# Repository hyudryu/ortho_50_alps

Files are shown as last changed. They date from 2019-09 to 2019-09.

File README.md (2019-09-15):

## Ortholinear 50% Keyboard: Alps Switch Plate and Case



#### Sample Layout:


#### Wiring Example:


#### Switch Plate:


#### Case Renders:




### 5x12 ortholinear keyboard switch plate for use with Alps switches.
* Inspired by the layout of the AMJ-40 keyboard, with an additional row for number keys.
* Kit works really well with an AEK-II, you can achieve a decent hacked together profile as pictured at the top.
* Bottom row intended to have a 2.75u spacebar and an adjacent 1.25u 3rd layer key.
* Spacerbar stabilizer mounting holes are designed for Alps OEM stabilizer not Cherry MX style stabs.
    * The spacebar can be mounted flipped, or normally.

### Assembly:
* The plate and case are intended to be joined with small screws, however, there are no holes in the parts. Feel free to add this but I chose to make them manually.
* The rear cutout is designed for a mini usb connection, like the one on the Teensy2.0.

### Note:
* Case cad files contain supports that will need to be trimmed off after printing, feel free to remove them if you want to print without them.
* Switch fitment is very tight when the plate is 3D printed at 2mm thickness. Trimming was definitely required in my case.
* Zero fitment guarantee, in fact, I guarantee you will have to fine tune the fit if printing.
* STL files may be misoriented for printing, thoroughly inspect files before continuing to print.
* Default firmware does not include any LED configuration.

###### Model was created in Solidworks, then exported as STL/DXF. Feel free to use/modify/redistribute.

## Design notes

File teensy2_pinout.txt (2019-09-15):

Using ATmega 32U4 controller:

Pins: row # : wire color
========================
F0 : r0 : wht
F1 : r1 : yel
F4 : r2 : red
F5 : r3 : grn
F6 : r4 : blu

Pins: column # : wire color
===========================
B7 : c0 : wht
D0 : c1 : yel
D1 : c2 : red
D2 : c3 : grn
D3 : c4 : blu
C6 : c5 : blk
C7 : c6 : blk
D7 : c7 : blu
B4 : c8 : grn
B5 : c9 : red
B6 : c10 : yel
F7 : c11 : wht

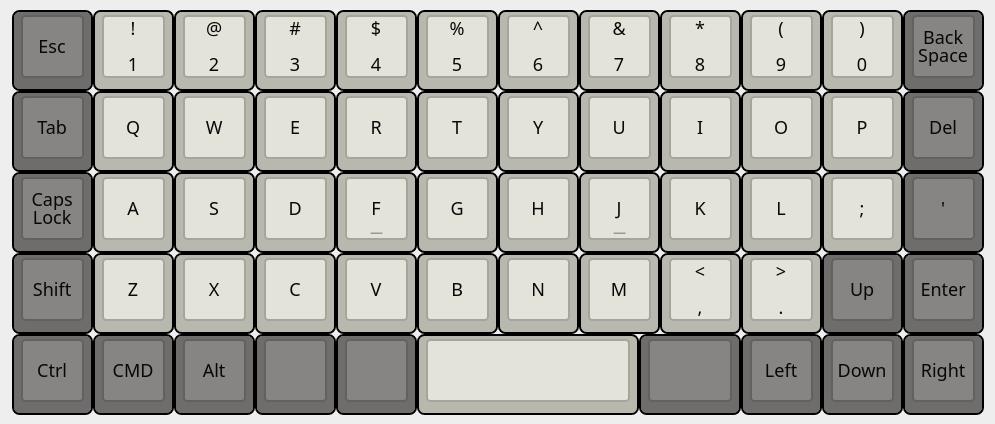
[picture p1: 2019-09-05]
ortho_50_layout.jpg

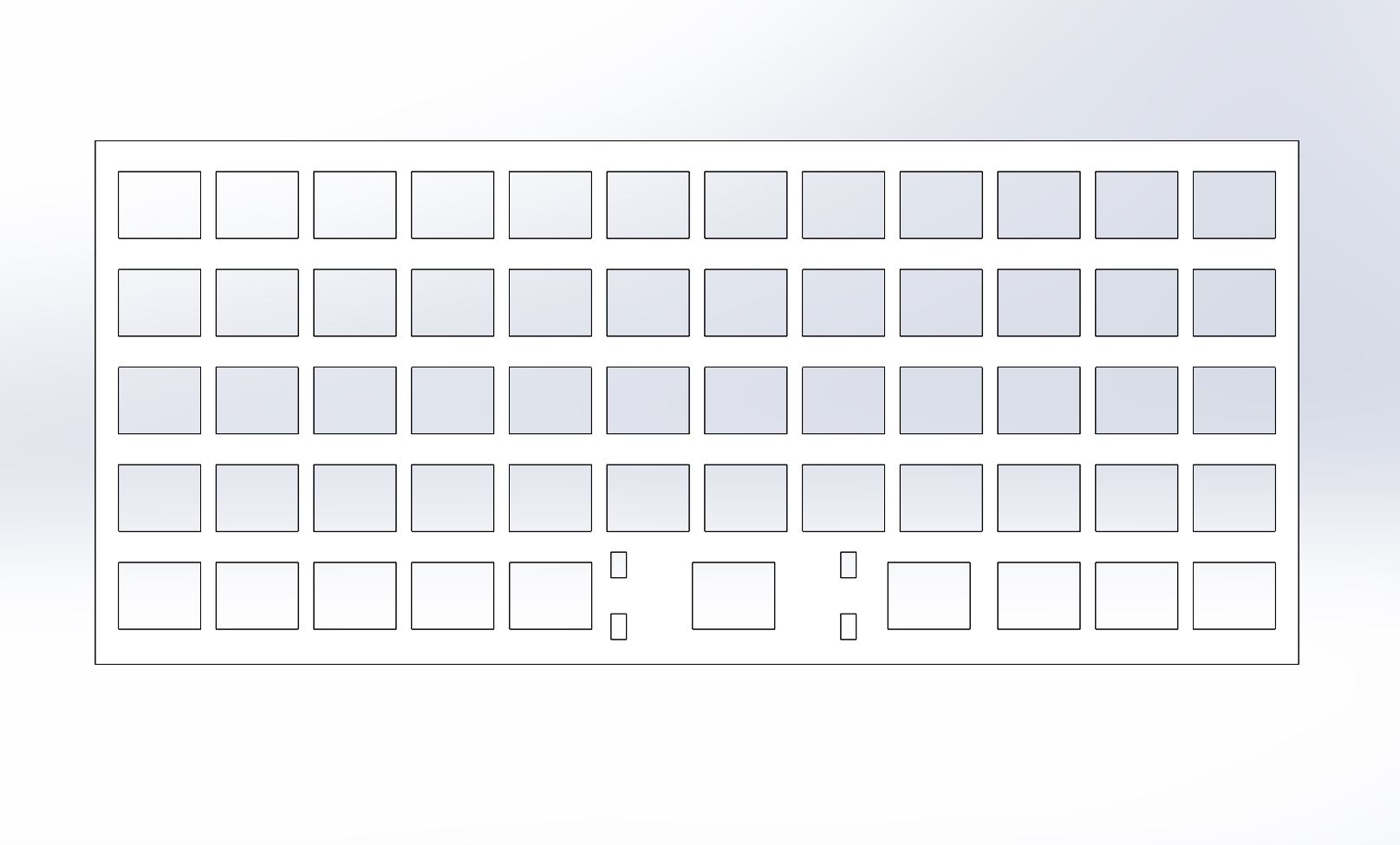
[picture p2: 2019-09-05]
ortho_50_plate.jpeg

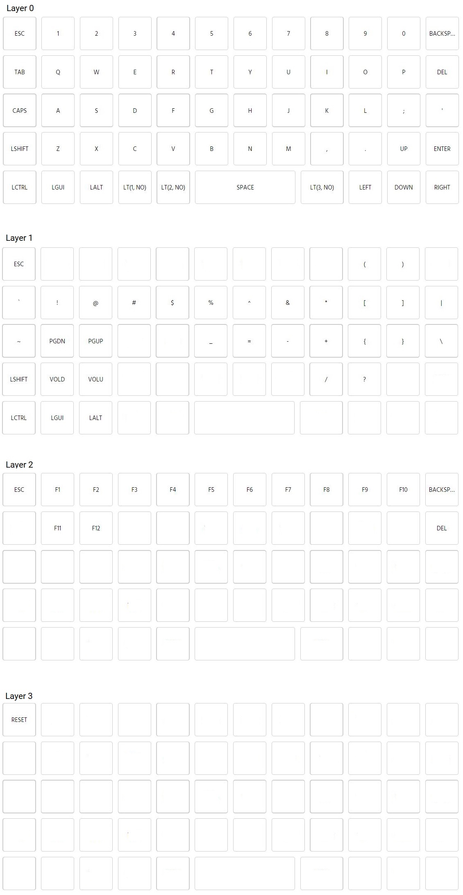
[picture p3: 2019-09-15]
ortho_50_keymap.jpg

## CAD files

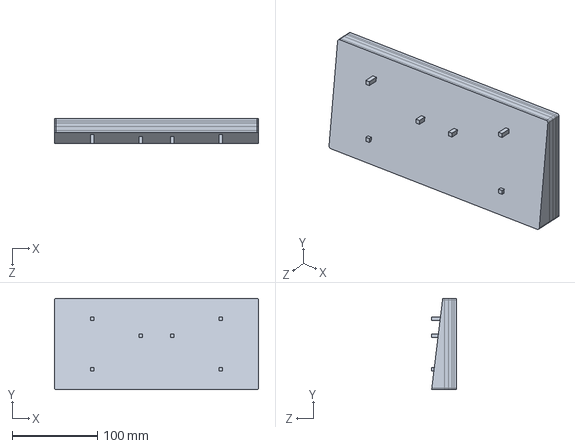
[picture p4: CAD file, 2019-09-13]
ortho_50_case.SLDPRT
239.0 x 106.8 x 29.0 mm

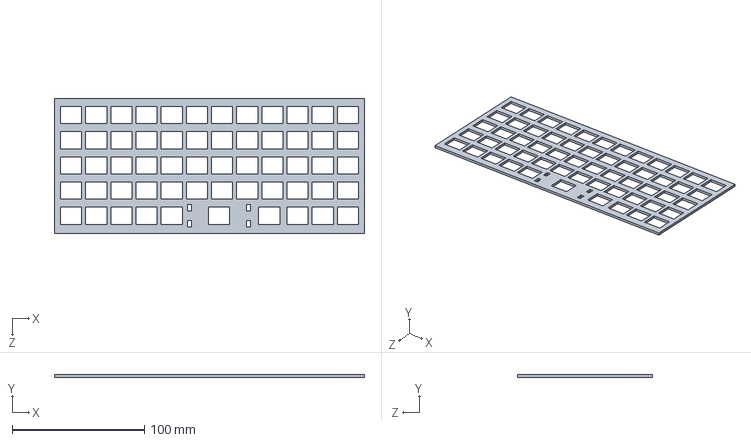
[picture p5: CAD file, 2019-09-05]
ortho_50_plate.SLDPRT
234.0 x 2.00 x 101.8 mm

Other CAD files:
ortho_50_case.STL
ortho_50_case.obj
ortho_50_plate.DXF
ortho_50_plate.STL

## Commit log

2019-09-06 added DXF file
    [aluminum_plate.DXF]
2019-09-12 added case files, added photo with aek caps
    [aluminum_plate.DXF, aluminum_plate.SLDPRT, aluminum_plate.STL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]
2019-09-13 extended plate supports to correct height in sldprt and stl files
    [ortho_50_case.SLDPRT, ortho_50_case.STL]
2019-09-15 added text file pinout of teensy2.0 controller
2019-09-15 added obj case file
    [ortho_50_case.obj]
